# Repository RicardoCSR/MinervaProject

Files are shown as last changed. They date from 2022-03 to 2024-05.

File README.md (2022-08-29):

# MinervaProject

Registro Mestre de Projeto 

Bases e arquivos de apoio utilizados para o desenvolvimento do projeto:

STM32duino - IDE Arduino Ver.1 e Ver.2

- Fontes TTL 
https://github.com/FrankBoesing/fonts.git
- Display TFT SPI/I2C
https://github.com/Bodmer/TFT_eSPI
- FontConverter - 1
https://rop.nl/truetype2gfx/
- FontConverter - 2
https://oleddisplay.squix.ch/#/home
- RGB888 para RGB565
https://trolsoft.ru/ru/articles/rgb565-color-picker
- App (EM TESTE)
https://thunkable.com/#/

Nixie_Clock - Extensor de Sensores de Sobrevivência

Iniciando em 16/10/2021

Projeto Minerva da paixão pelos clássicos tubos Nixie desenvolvidos na década de 50 aos modernos display LCD, da inspiração veio junto o desafio de unir o antigo ao novo agregando diversos sensores para a apresentação de informações para uso e sobrevivência diário como:

- Pressão (mmHg)
- Temperatura (ºC e F)
- Umidade (%)
- Altitude
- sieverts (µSv e mSv)
- Hora/Data
- Calendário Completo
- Calculadora
- Grandezas e Medidas
- Estação do Ano (Primavera)
- Semana (Semana 39)
- Modo de ajustes dos parâmetros 

Sendo organizados pelos Menus:

Geiger                              - Apresenta Contagem por Segundo, Leitura Sieverts nSv/s
Dosimeter                           - Apresenta valor Dosimetro, Tempo de atualização, faixa de risco de Sv/h
Geiger GF                           - Apresenta gráfico dos valores apresentados nas 24 Horas do Geiger
Calendar                            - Apresenta Calendário
Timer                               - Apresenta Alarme, Contador e Tempo de Volta
Weather GF Temperature              - Apresenta gráfico dos valores apresentados nas 24 Horas do Temperatura
Weather GF Humidity                 - Apresenta gráfico dos valores apresentados nas 24 Horas do Umidade
Weather GF Atmosferic Pressure      - Apresenta gráfico dos valores apresentados nas 24 Horas do Pressão Atmosferica
Weather                             - Apresenta Temperatura, Umidade, Pressão Atmosférica, mínima e máxima e previsão via 
User                                - Apresenta Configurações básica de nome e imagem de Perfil
Calculator                          - Apresenta Calculadora de Operação Simples (Modendo ser extender a outros modelos)
Gerador de Sinais                   - Apresenta função de gerador de Sinais de 3.3V
Nixie Settings                      - Apresenta ajuste de animação Nixie
WiFi Settings                       - Apresenta Configurações de Acesso a rede externa
Settings                            - Apresenta Configurações de Ajuste da Tela

Database                            - Apresenta valores de todas as variaveis presentes (USO DESENVOLVIMENTO).

Componentes e suas caracteristicas

SN74141 : True Table // Podendo utilizar k155id1 ou SN74141
- D C B A #
- L, L, L, L 0
- L, L, L, H 1
- L, L, H, L 2
- L, L, H, H 3
- L, H, L, L 4
- L, H, L, H 5
- L, H, H, L 6
- L, H, H, H 7
- H, L, L, L 8
- H, L, L, H 9
- H, L, H, L N
- H, L, H, H N
- H, H, L, L N
- H, H, L, H N
- H, H, H, L N
- H, H, H, H N

ILI9486_DRIVER - Alimentação Ideal 3v3
TFT 8-BIT PARALLEL

Lista Terminais Utilizados STM32L476RG  29/08/2022

- R       Botao Hard Reset (Apenas para Desenvolvimento)

- PA0     TFT_RD
- PA1     TFT_WD
- PA2     
- PA3     
- PA4     TFT_DC
- PA5     
- PA6    
- PA7     
- PA8     TFT_D7
- PA9     TFT_D1
- PA10    TFT_D2
- PA11    
- PA12    
- PA15    

- PB0     TFT_CS
- PB1    
- PB2     
- PB3     TFT_D3
- PB4     TFT_D5
- PB5     TFT_D4
- PB6     
- PB7     
- PB8     
- PB9     
- PB10    TFT_D6
- PB12   
- PB13    
- PB14  
- PB15   

- PC0
- PC1     TFT_RST
- PC2
- PC3
- PC4
- PC5
- PC6
- PC7     TFT_D0
- PC8
- PC9
- PC10
- PC11
- PC12
- PC13   
- PC14    
- PC15    

- PD2

- PH0
- PH1

Lista Terminais Utilizados ESP32S  29/08/2022

- R       Botao Hard Reset

- GPIO0
- GPIO1
- GPIO2
- GPIO3
- GPIO4
- GPIO6
- GPIO7
- GPIO8
- GPIO9
- GPIO10
- GPIO11
- GPIO12
- GPIO13
- GPIO14
- GPIO15
- GPIO16
- GPIO17
- GPIO18
- GPIO19
- GPIO21
- GPIO22
- GPIO23
- GPIO25
- GPIO26
- GPIO27
- GPIO32
- GPIO33
- GPIO34
- GPIO35
- GPIO36
- GPIO39

*Projeto alterado para a Rev.3 sendo substituido o display ST7789 para o modelo ILI9486 de 480x320 em 8-Bit Paralelo pela velocidade de carregamento e estabilidade durante execuções e aplicações que envolvem banco de dados. O microcontrolador anterior STM32F401CCU6 substituido pelo modelo STM32L476RG de maior banda de memoria e expansão. Podendo ser substituido por um modelo mais economico.

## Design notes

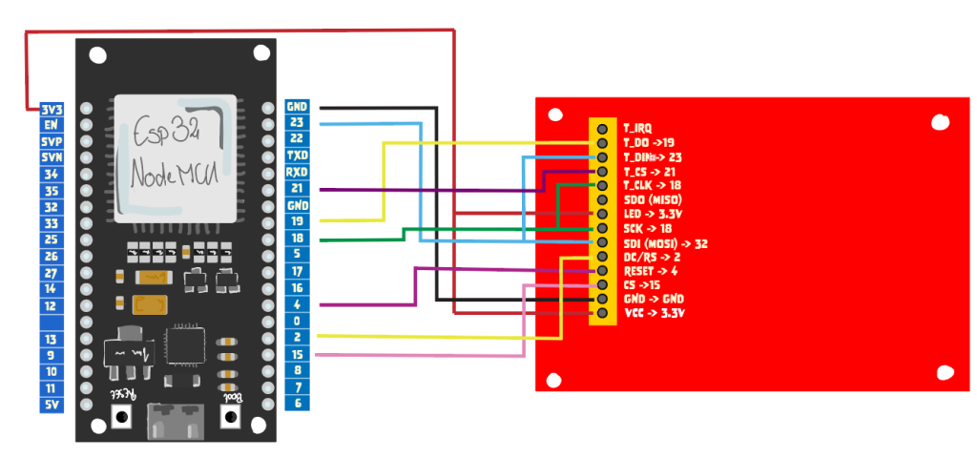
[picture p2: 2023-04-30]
esp32ScreenPinout.webp

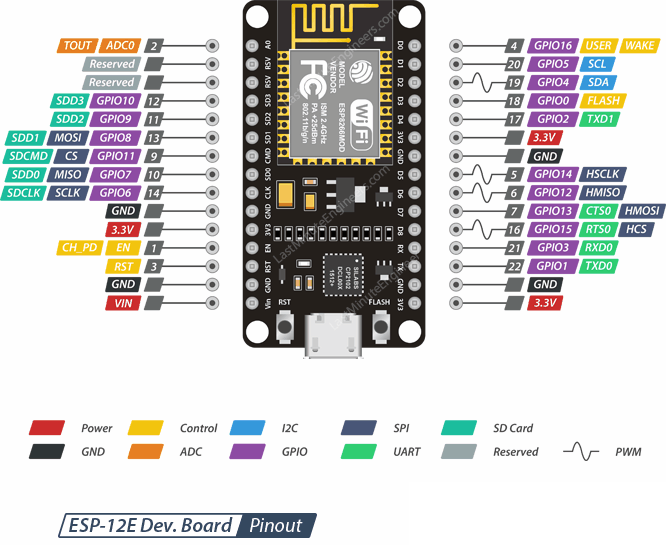
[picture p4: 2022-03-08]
ESP12E 8266.png

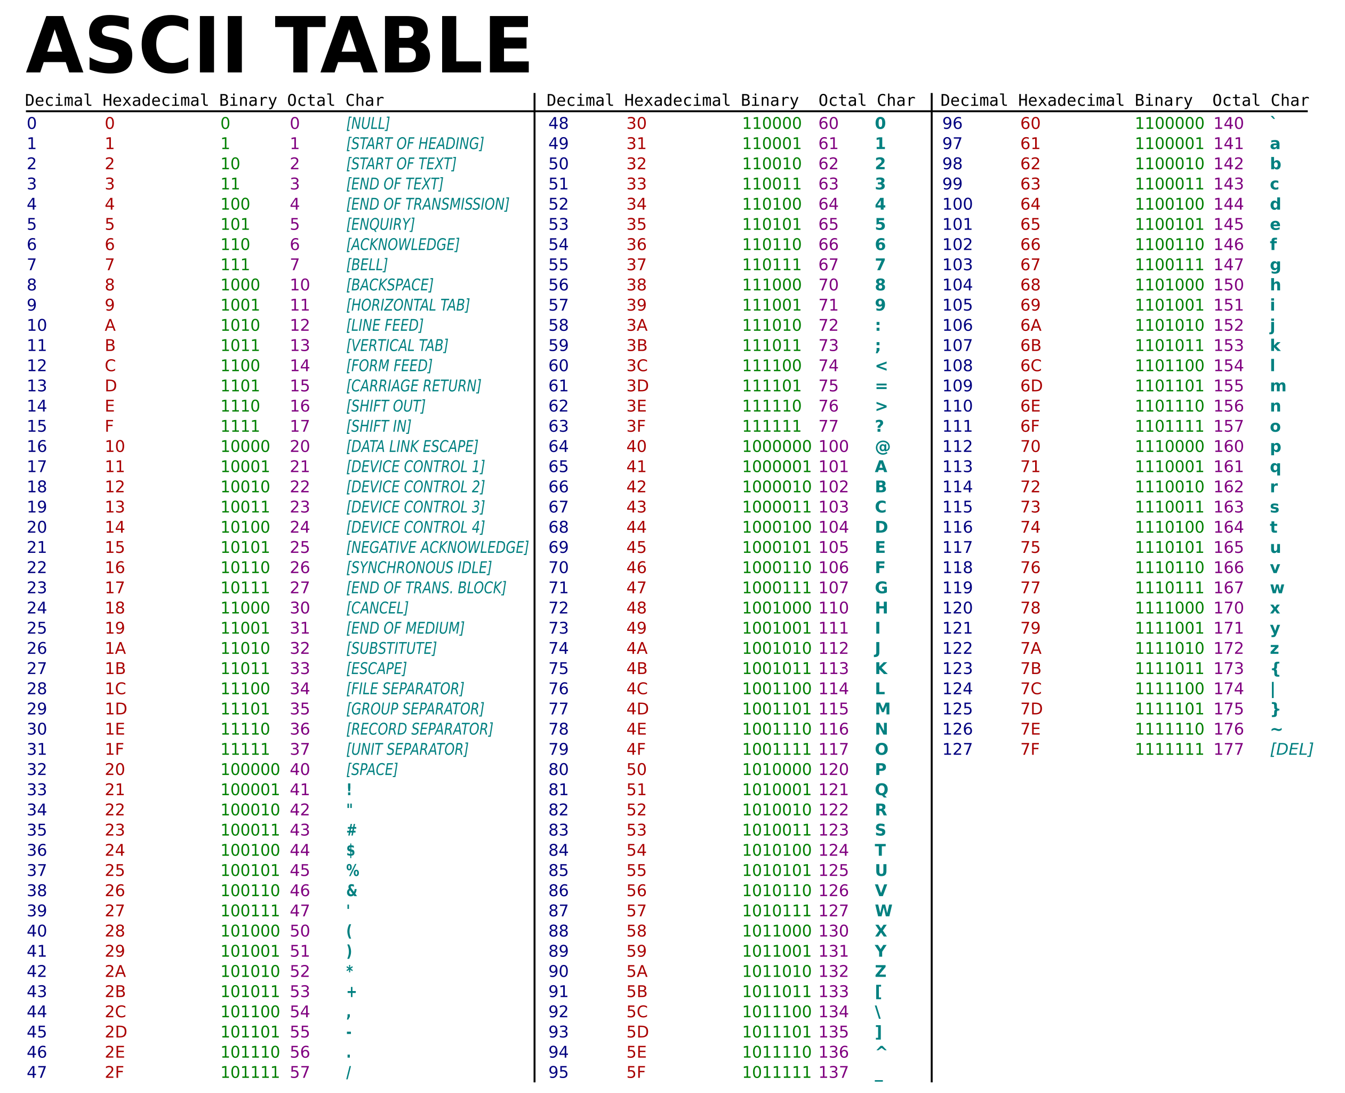
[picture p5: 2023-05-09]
ASCII-Table.svg.png

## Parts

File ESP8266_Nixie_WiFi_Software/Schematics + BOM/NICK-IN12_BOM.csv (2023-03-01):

ID | Name | Designator | Footprint | Quantity | Manufacturer Part | Manufacturer | Supplier | Supplier Part | LCSC Assembly
1 | 10uF | C3 | CAP_0603 | 1 | TCC0603X5R106M160CT | CCTC | LCSC | C380317
2 | 330 | R6,R7 | R0603 | 2 | 0603WAJ0331T5E | UniOhm | LCSC | C25231
3 | K155ID1/SN74141 | U3,U4,U5,U6 | DIP16 | 4
4 | TLP627-2(F) | U8 | PDIP-8_L9.5-W6.6-P2.54-LS8.0-BL | 1 | TLP627-2(F) | TOSHIBA | LCSC | C845530
5 | MMBT2222A,215 | Q1 | SOT-23-3_L2.9-W1.6-P1.90-LS2.8-BR | 1 | MMBT2222A,215 | Nexperia | LCSC | C179396 | Yes
6 | 74HC595D,118 | U1,U2 | SOIC-16_150MIL | 2 | 74HC595D,118 | Nexperia | LCSC | C5947 | Yes
7 | U-D-M5DD-W-1 | USB1 | MICRO-USB-TH_MICRO-USB-A14 | 1 | U-D-M5DD-W-1 | HRO | LCSC | C145795
8 | 1A FUSE | F1 | FUSE_0805 | 1 | SMD0805P110TF | Yenji Elec | LCSC | C393933
9 | 100nF | C1,C4,C5 | 0603 | 3 | C0603C104K5RACTU | KEMET | LCSC | C127833
10 | WS2812B | LED1,LED2,LED3,LED4,LED5 | LED-5050_4P | 5 | WS2812B | Worldsemi | LCSC | C114585
11 | NCH8200HV | PS1 | NCH8200HV-1 | 1 | NCH8200HV
12 | 10K | R1,R8,R9 | RES_0603 | 3 | PTFR0603D10K0P9 | ResistorToday | LCSC | C375971
13 | 20K | R2,R3,R4,R5 | 1210 | 4 | RC1210JR-0720KL | YAGEO | LCSC | C276323
14 | AMS1117-3.3_C351784 | U7 | SOT-223-3_L6.5-W3.4-P2.30-LS7.0-BR | 1 | AMS1117-3.3 | PUOLOP | LCSC | C351784
15 | 470uF | C2 | CASE-D_7343 | 1 | TAJD477M006RNJ | AVX | LCSC | C106188 | Yes
16 | SW_IN-12B | NIX1,NIX2,NIX3,NIX4 | PK_IN-12B | 4
17 | 1N5819 | D1 | SOD-323_L1.8-W1.3-LS2.5-RD | 1 | 1N5819WS | KEXIN | LCSC | C369937
18 | ESP-12E | ESP | WIFIM-SMD_ESP-12E | 1 | ESP-12E | Ai-Thinker | LCSC | C89297

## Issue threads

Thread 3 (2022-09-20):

Grafico Deslocado

RicardoCSR, 2022-09-20:
Durante a execução dos gráficos o mesmo não ultrapassa as **12 Horas** indicadas. _Verificar a conversão e sistema de armazenamento dos valores de escrita e posicionamento de barra._

RicardoCSR, 2023-04-30:
Falha apresentada com o valor const alterado com a nova versao do software

Closed 2023-04-30.

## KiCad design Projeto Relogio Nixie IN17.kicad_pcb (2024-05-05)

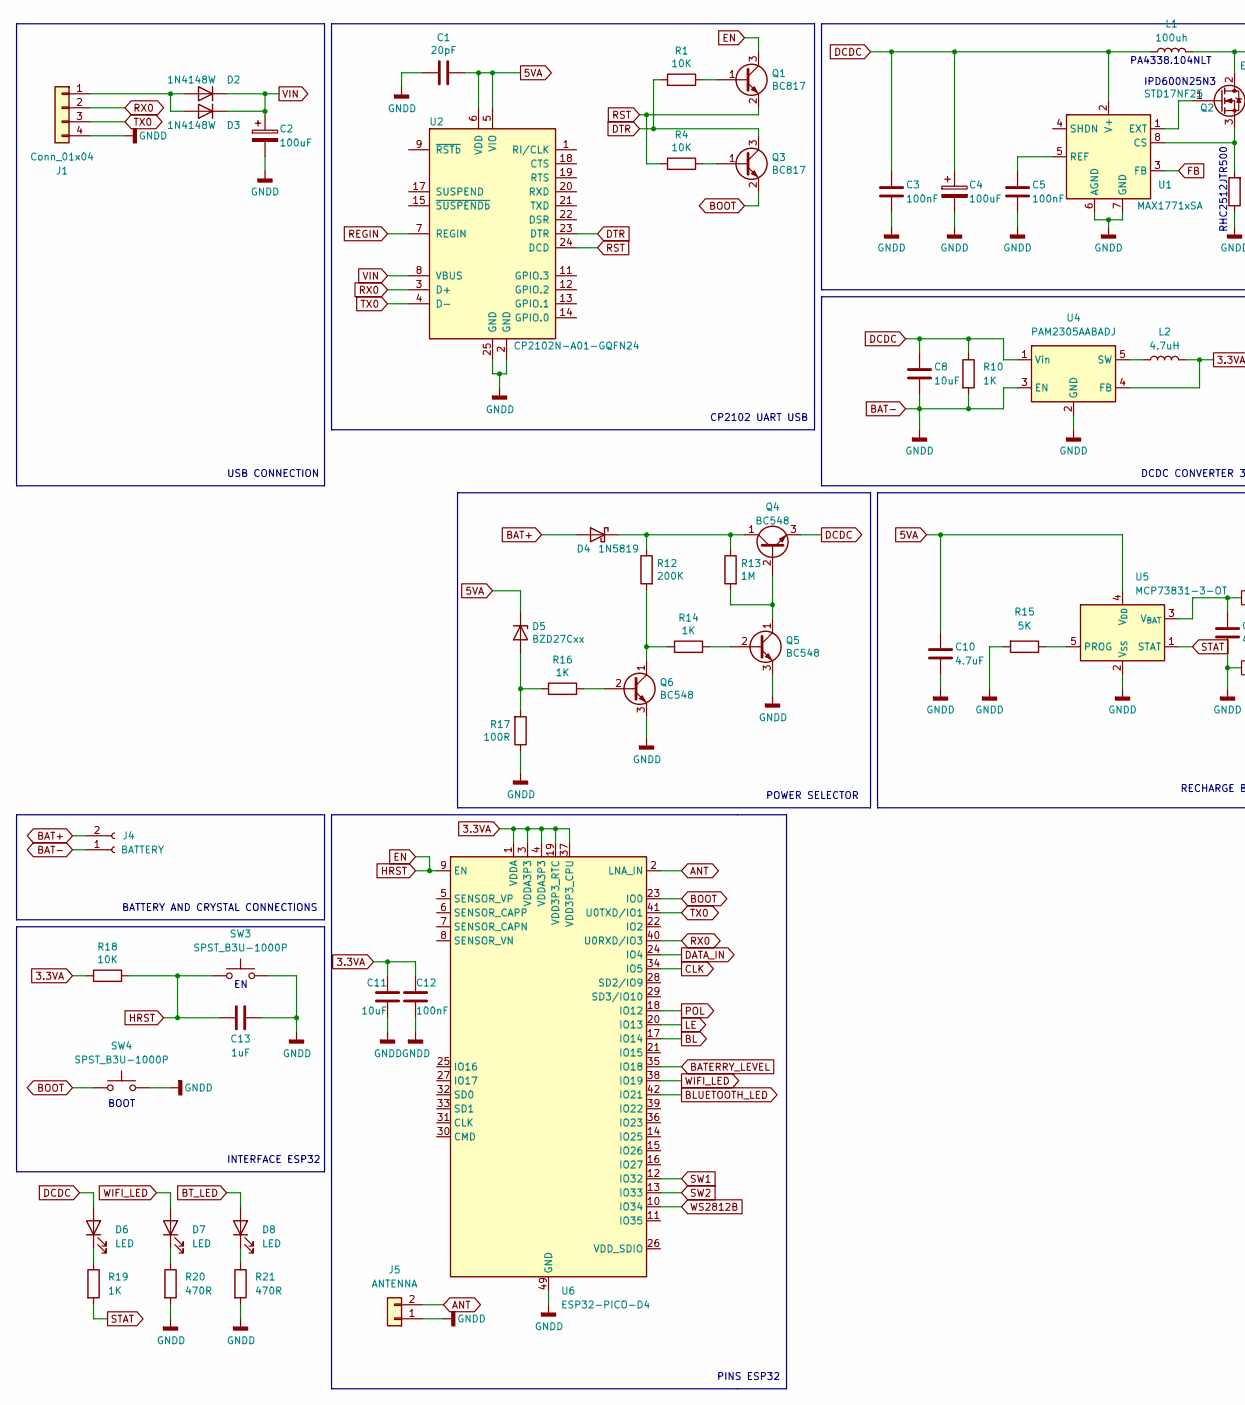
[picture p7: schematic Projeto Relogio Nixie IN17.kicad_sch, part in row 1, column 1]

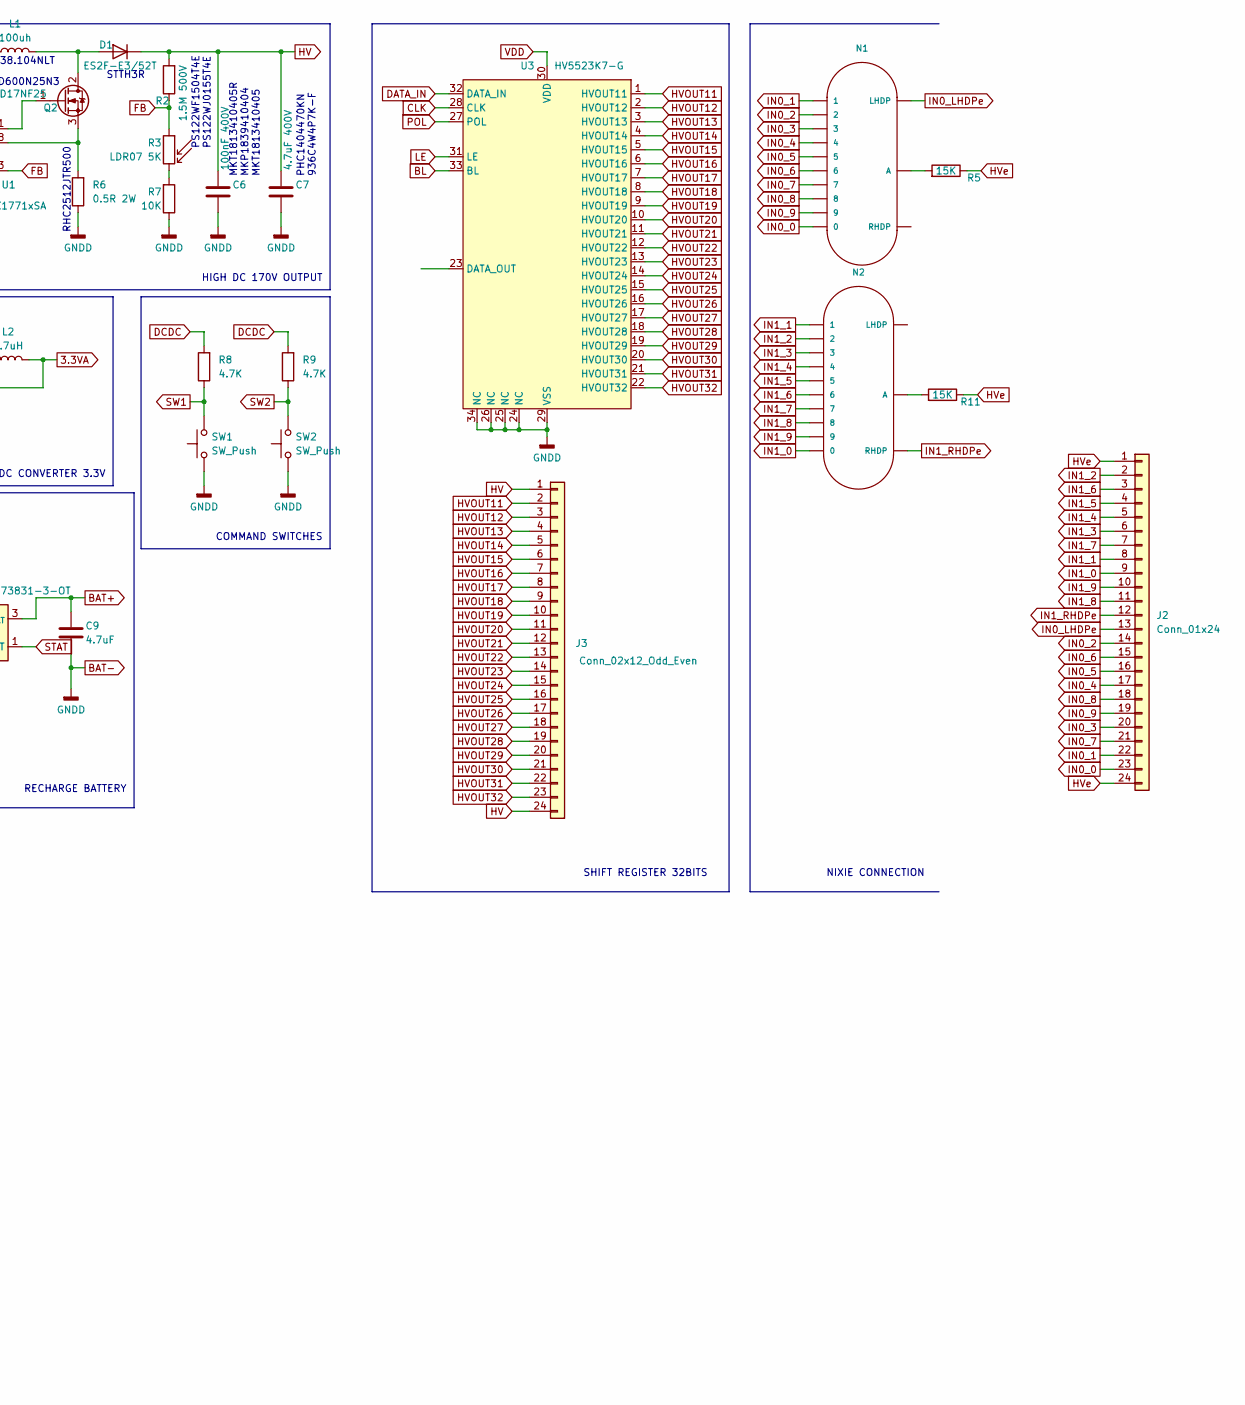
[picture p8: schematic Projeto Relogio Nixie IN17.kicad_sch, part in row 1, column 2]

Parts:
C1: 20pF; C_0805_2012Metric
C2, C4: 100uF; CP_EIA-1608-08_AVX-J
C3, C5, C12: 100nF; C_0805_2012Metric
C6: 100nF 400V; C_Axial_L5.1mm_D3.1mm_P10.00mm_Horizontal
C7: 4.7uF 400V; C_Axial_L5.1mm_D3.1mm_P10.00mm_Horizontal
C8, C11: 10uF; C_0805_2012Metric
C9, C10: 4.7uF; C_0805_2012Metric
C13: 1uF; C_0805_2012Metric
D1: ES2F-E3/52T; D_SMB
D2, D3: 1N4148W; D_SOD-123
D4: 1N5819; D_0805_2012Metric
D5: BZD27Cxx; D_2114_3652Metric
D6, D7, D8: LED; LED_1206_3216Metric
J1: Conn_01x04; Magnetic_01x04
J2: Conn_01x24; TE_2-1734839-4_1x24-1MP_P0.5mm_Horizontal
J3: Conn_02x12_Odd_Even; TE_2-1734839-4_1x24-1MP_P0.5mm_Horizontal
J4: BATTERY; PinHeader_1x02_P2.00mm_Vertical
J5: ANTENNA; PinHeader_1x02_P2.00mm_Vertical
L1: 100uh; L_Bourns-SRN8040_8x8.15mm
L2: 4.7uH; L_Bourns_SRP5030T
N1, N2: IN-16; nixies-us-IN-16
Q1, Q3: BC817; SOT-23
Q2: STD17NF25; TO-252-2
Q4, Q5, Q6: BC548; SOT-23
R1, R4, R7, R18: 10K; R_0603_1608Metric
R2: 1.5M 500V; R_2512_6332Metric_Pad1.40x3.35mm_HandSolder
R3: LDR07 5K; R_LDR_5.1x4.3mm_P3.4mm_Vertical
R5, R11: 15K; R_0603_1608Metric
R6: 0.5R 2W; R_2512_6332Metric_Pad1.40x3.35mm_HandSolder
R8, R9: 4.7K; R_0603_1608Metric
R10, R14, R16, R19: 1K; R_0603_1608Metric
R12: 200K; R_0603_1608Metric
R13: 1M; R_0603_1608Metric
R15: 5K; R_0603_1608Metric
R17: 100R; R_0603_1608Metric
R20, R21: 470R; R_0603_1608Metric
SW1, SW2: SW_Push; PinHeader_1x02_P2.00mm_Vertical
SW3, SW4: SPST_B3U-1000P; SW_SPST_B3U-1000P
U1: MAX1771xSA; SO-8_3.9x4.9mm_P1.27mm
U2: CP2102N-A01-GQFN24; QFN-24-1EP_4x4mm_P0.5mm_EP2.6x2.6mm
U3: HV5523K7-G; QFN-44-1EP_7x7mm_P0.5mm_EP5.15x5.15mm
U4: PAM2305AABADJ; TSOT-23-5
U5: MCP73831-3-OT; SOT-23-5
U6: ESP32-PICO-D4; QFN-48-1EP_7x7mm_P0.5mm_EP5.3x5.3mm

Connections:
3.3VA: C11.1, C12.1, L2.2, R18.2, U4.4 (FB), U6.1 (VDDA), U6.3 (VDDA3P3), U6.4 (VDDA3P3), U6.19 (VDD3P3_RTC), U6.37 (VDD3P3_CPU)
5VA: C1.1, C10.1, D5.1 (K), U2.5 (VIO), U2.6 (VDD), U5.4 (V_{DD}); also elsewhere on the board
ANT: J5.2, U6.2 (LNA_IN)
BAT+: C9.1, D4.2 (A), J4.2, U5.3 (V_{BAT})
BAT-: C1.2, C2.2, C3.2, C4.2, C5.2, C6.2, C7.2, C8.2, C9.2, C10.2, C11.2, C12.2, C13.2, J1.4, J4.1, J5.1, Q5.3 (E), Q6.3 (E), R6.1, R7.1, R10.2, R15.2, R17.1, R20.2, R21.2, SW1.1, SW2.1, SW3.3 (B), SW3.4 (B), SW4.3 (B), SW4.4 (B), U1.6 (AGND), U1.7 (GND), U2.2 (GND), U2.25 (GND), U3.24 (NC), U3.25 (NC), U3.26 (NC), U3.29 (VSS), U3.34 (NC), U4.2 (GND), U4.3 (EN), U5.2 (V_{SS}), U6.49 (GND)
BATERRY_LEVEL: U6.35 (IO18)
BL: U3.33 (BL), U6.17 (IO14)
BLUETOOTH_LED: U6.42 (IO21)
BOOT: Q3.2 (E), SW4.1 (A), SW4.2 (A), U6.23 (IO0)
BT_LED: D8.2 (A)
CLK: U3.28 (CLK), U6.34 (IO5)
DATA_IN: U3.32 (DATA_IN), U6.24 (IO4)
DCDC: C3.1, C4.1, C8.1, D6.2 (A), L1.1, Q4.3 (E), R8.2, R9.2, R10.1, U1.2 (V+), U4.1 (Vin)
DTR: Q3.3 (C), R1.2, U2.23 (DTR)
EN: C13.1, Q1.3 (C), R18.1, SW3.1 (A), SW3.2 (A), U6.9 (EN)
FB: R2.1, R3.1, U1.3 (FB)
HV: C6.1, C7.1, D1.1 (K), J3.1, J3.24, R2.2
HVOUT11: J3.2, U3.1 (HVOUT11)
HVOUT12: J3.3, U3.2 (HVOUT12)
HVOUT13: J3.4, U3.3 (HVOUT13)
HVOUT14: J3.5, U3.4 (HVOUT14)
HVOUT15: J3.6, U3.5 (HVOUT15)
HVOUT16: J3.7, U3.6 (HVOUT16)
HVOUT17: J3.8, U3.7 (HVOUT17)
HVOUT18: J3.9, U3.8 (HVOUT18)
HVOUT19: J3.10, U3.9 (HVOUT19)
HVOUT20: J3.11, U3.10 (HVOUT20)
HVOUT21: J3.12, U3.11 (HVOUT21)
HVOUT22: J3.13, U3.12 (HVOUT22)
HVOUT23: J3.14, U3.13 (HVOUT23)
HVOUT24: J3.15, U3.14 (HVOUT24)
HVOUT25: J3.16, U3.15 (HVOUT25)
HVOUT26: J3.17, U3.16 (HVOUT26)
HVOUT27: J3.18, U3.17 (HVOUT27)
HVOUT28: J3.19, U3.18 (HVOUT28)
HVOUT29: J3.20, U3.19 (HVOUT29)
HVOUT30: J3.21, U3.20 (HVOUT30)
HVOUT31: J3.22, U3.21 (HVOUT31)
HVOUT32: J3.23, U3.22 (HVOUT32)
HVe: J2.1, J2.24, R5.1, R11.1
IN0_0: J2.23, N1.0
IN0_1: J2.22, N1.1
IN0_2: J2.14, N1.2
IN0_3: J2.20, N1.3
IN0_4: J2.17, N1.4
IN0_5: J2.16, N1.5
IN0_6: J2.15, N1.6
IN0_7: J2.21, N1.7
IN0_8: J2.18, N1.8
IN0_9: J2.19, N1.9
IN0_LHDPe: J2.13, N1.LHDP
IN1_0: J2.9, N2.0
IN1_1: J2.8, N2.1
IN1_2: J2.2, N2.2
IN1_3: J2.6, N2.3
IN1_4: J2.5, N2.4
IN1_5: J2.4, N2.5
IN1_6: J2.3, N2.6
IN1_7: J2.7, N2.7
IN1_8: J2.11, N2.8
IN1_9: J2.10, N2.9
IN1_RHDPe: J2.12, N2.RHDP
LE: U3.31 (LE), U6.20 (IO13)
unnamed: D1.2 (A), L1.2, Q2.2 (D)
unnamed: D2.2 (A), D3.2 (A), J1.1
unnamed: D4.1 (K), Q4.1 (C), R12.1, R13.1
unnamed: D5.2 (A), R16.2, R17.2
unnamed: D6.1 (K), R19.1
unnamed: D7.1 (K), R20.1
unnamed: D8.1 (K), R21.1
unnamed: N1.A, R5.2
unnamed: N2.A, R11.2
unnamed: Q1.1 (B), R1.1
unnamed: Q2.1 (G), U1.1 (EXT)
unnamed: Q2.3 (S), R6.2, U1.8 (CS)
unnamed: Q3.1 (B), R4.1
unnamed: Q4.2 (B), Q5.1 (C), R13.2
unnamed: Q5.2 (B), R14.1
unnamed: Q6.2 (B), R16.1
unnamed: Q6.1 (C), R12.2, R14.2
unnamed: R3.2, R7.2
unnamed: C5.1, U1.5 (REF)
unnamed: L2.1, U4.5 (SW)
unnamed: R15.1, U5.5 (PROG)
POL: U3.27 (POL), U6.18 (IO12)
REGIN: U2.7 (REGIN)
RST: Q1.2 (E), R4.2, U2.24 (DCD)
RX0: J1.2, U2.3 (D+), U6.40 (U0RXD/IO3)
STAT: R19.2, U5.1 (STAT)
SW1: R8.1, SW1.2, U6.12 (IO32)
SW2: R9.1, SW2.2, U6.13 (IO33)
TX0: J1.3, U2.4 (D-), U6.41 (U0TXD/IO1)
VDD: U3.30 (VDD)
VIN: C2.1, D2.1 (K), D3.1 (K), U2.8 (VBUS); also elsewhere on the board
WIFI_LED: D7.2 (A), U6.38 (IO19)
WS2812B: U6.10 (IO34)

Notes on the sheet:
CP2102 UART USB
POWER SELECTOR
COMMAND SWITCHES
PA4338.104NLT
PHC1404470KN 936C4W4P7K-F
RHC2512JTR500
INTERFACE ESP32
DCDC CONVERTER 3.3V
IPD600N25N3
HIGH DC 170V OUTPUT
BATTERY AND CRYSTAL CONNECTIONS
BOOT
PINS ESP32
USB CONNECTION
STTH3R
SHIFT REGISTER 32BITS
NIXIE CONNECTION
PS122WF1504T4E PS122WJ0155T4E
RECHARGE BATTERY
MKT1813410405R MKP1839410404 MKT1813410405

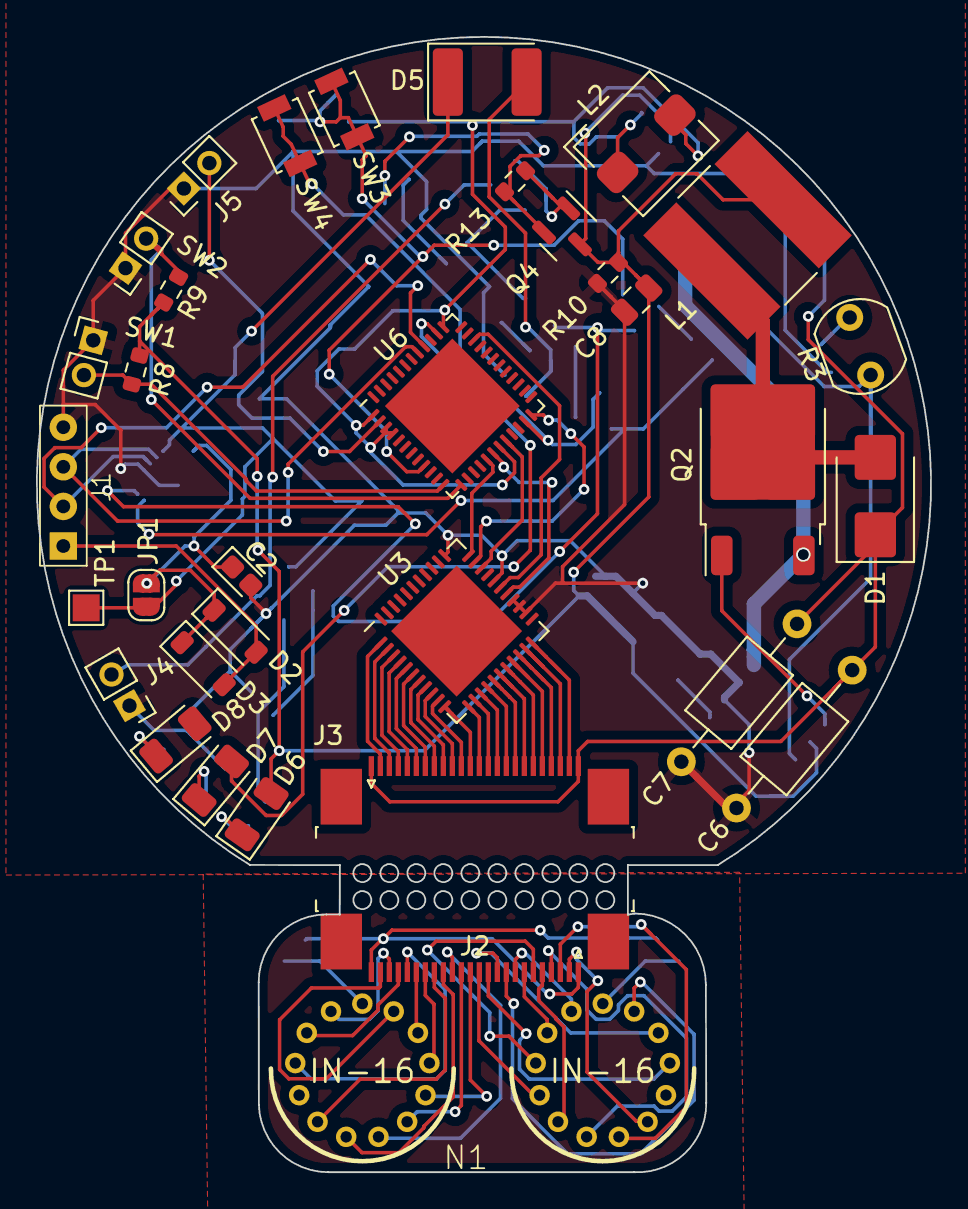
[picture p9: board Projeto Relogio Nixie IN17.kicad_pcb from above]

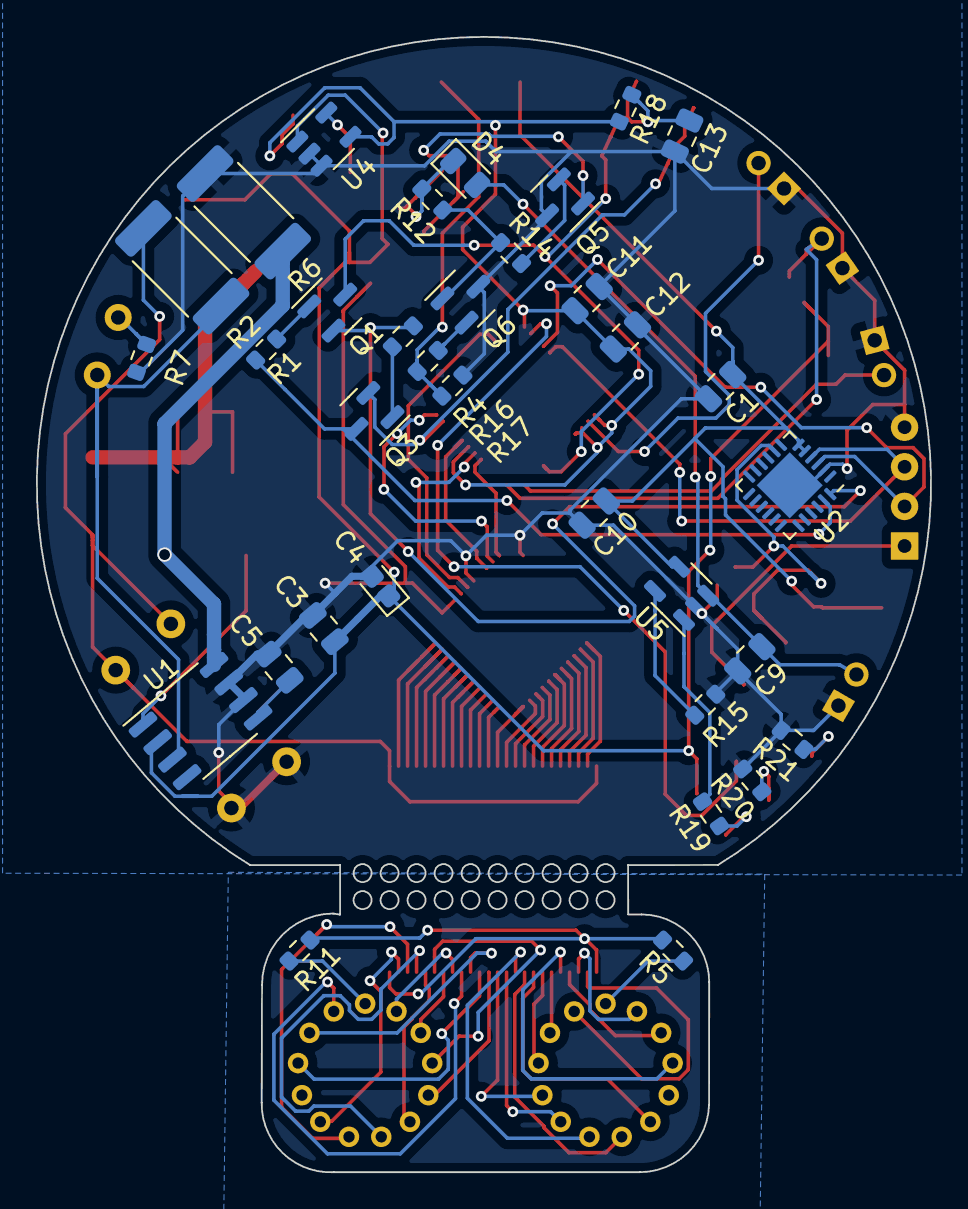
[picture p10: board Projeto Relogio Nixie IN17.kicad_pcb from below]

Board: 2 copper layers, 49.7 x 63.1 mm, 69 parts (34 on the bottom side), 90 nets.

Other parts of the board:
JP1: SolderJumper-2_P1.3mm_Open_RoundedPad1.0x1.5mm
TP1: 5VA; TestPoint_Pad_1.5x1.5mm

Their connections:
5VA: JP1.2 (B), TP1.1; also elsewhere on the board
VIN: JP1.1 (A); also elsewhere on the board

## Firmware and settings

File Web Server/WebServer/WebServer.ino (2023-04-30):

// Inclusão das bibliotecas
#include <WiFi.h>
#include <AsyncTCP.h>
#include <ESPAsyncWebServer.h>

// Instanciação do objeto da classe AsyncWebServer
AsyncWebServer server(80);

// Constantes das credenciais do WiFi
const char* ssid = "Ricardo-EvolutionPro-2G";
const char* password = "ricardo123";

void setup() {

  // Conecta-se ao Ponto de acesso com as credenciais fornecidas
  WiFi.begin(ssid, password);

  // disponibiliza o url "/"
  server.on("/", HTTP_GET, [](AsyncWebServerRequest * request) {
    const char index_html[] PROGMEM = R"====(

<!DOCTYPE html>
<html lang="pt-br">
    <link rel="stylesheet" href="https://fonts.googleapis.com/css?family=Lato:300">
    <head>
       <meta charset="utf-8"/>
       <title>Welcome</title>
       
    </head>

    <script>
        const scrollBars = document.querySelectorAll('.scroll-bar');

        function updateScrollBars() {
        const scrollTop = document.documentElement.scrollTop;
        const scrollHeight = document.documentElement.scrollHeight;
        const clientHeight = document.documentElement.clientHeight;
        const scrollRatio = scrollTop / (scrollHeight - clientHeight);

        scrollBars.forEach((scrollBar, index) => {
            if (index / 4 <= scrollRatio) {
            scrollBar.classList.add('active');
            } else {
            scrollBar.classList.remove('active');
            }
        });
        }

        window.addEventListener('scroll', updateScrollBars);

    </script>
    <style>
        @import url('https://fonts.googleapis.com/css?family=Lato&display=swap');

        body {
            margin: 0;
            padding: 0;
            justify-content: center;
        }
        .header-container {
            
            display: flex;
            justify-content: flex-end;
            align-items: center;
            padding: 10px;
            background-color: #161616;
            color: white;
        }

        img {
            width: 50px;
            height: 50px;
            margin-left: 2%;
            margin-top: 5px;
            position: absolute;
        }

        .header-buttons {
            display: flex;
            justify-content: flex-end;
            align-items: center;
        }

        .botao-header {
            font-family: 'Gill Sans', 'Gill Sans MT', Calibri, 'Trebuchet MS', sans-serif;
            font-size: 18px;
            color: #c0c0c0;
            background-color: transparent;
            border: none;
            padding: 10px;
            cursor: pointer;
            margin-left: 10px;
            width: 90px;
        }

        .botao-header2 {
            font-family: 'Gill Sans', 'Gill Sans MT', Calibri, 'Trebuchet MS', sans-serif;
            font-weight: 600;
            font-size: 18px;
            background-color: #fff;
            color: #000000;
            border: none;
            padding: 10px;
            border-radius: 5px;
            cursor: pointer;
            margin-left: 20px;
            width: 100px;
            margin-right: 2%;
        }

        .botao-header:hover {
            border: none;
            border-radius: 5px;
            background-color: #ffffff;
            color: #000000;
        }
        .page1 {
            align-items: center;
            width: 100%;
            height: 500px;
            background-color: #161616;
        }
        .page2 {
            align-items: center;
            width: 100%;
            height: 500px;
            background-color: #F67423;
        }
        .page3 {
            align-items: center;
            width: 100%;
            height: 500px;
            background-color: #BE1D69;
        }
        .page4 {
            align-items: center;
            width: 100%;
            height: 500px;
            background-color: #33ACD1;
        }
        .page5 {
            align-items: center;
            width: 100%;
            height: 500px;
            background-color: #343A40;
        }

        .allinone {
            padding-top: 50px;
            display: flex;
            width: 85%;
            margin: 0 auto;
        }
        .gradient-box {
            position: relative;
            background: linear-gradient(to bottom right, rgba(0, 219, 222, 0.9) 0%, rgba(75, 25, 102, 1)55%, rgba(30,25,30, 0.9)); /* define o gradiente na diagonal */
            padding: 0px; /* adiciona algum espaço interno para o conteúdo */
            color: #fff; /* define a cor do texto para branco */
            border-radius: 30px;
            height: 340px;
            width: 60%;
        }

        .gradientimage {
            margin-top: 10px;
            margin-left: 15px;
            width: 55px;
            height: 55px;
        }

        .caixa {
            padding-top: 75px;
            padding-left: 35px;
            margin: 0 auto;
            width: 450px;
            height: 200px;
        }
        .caixa button {
            margin-right: 15px;
            margin-bottom: 15px;
        }

        .coluna {
            border-radius: 15px;
            border: none;
            width: 70px;
            height: 70px;
        }

        .text-box1 {
            line-height: 0px;
            right: 250px;
            position: absolute;
        }
        
        .text-box1 p {
            margin-top: 35px;
            font-size: 54px;
            color: #ffffff;
            font-family: 'Lato', sans-serif;
            font-weight: bold;
        }

        .h1page1 {
            line-height: 25px;
            width: 50px;
            text-align: right;
            color: #c0c0c0;
            font-family: 'Lato', sans-serif;
            font-weight: 300;
            font-size: 20px;
            padding: 0;
            width: 241px;
        }

        .text-box2 {
            line-height: 0px;
            left: 50px;
            position: absolute;
        }
        
        .text-box2 p {
            margin-top: 125px;
            font-size: 54px;
            color: #ffffff;
            font-family: 'Lato', sans-serif;
            font-weight: bold;
        }

        .h1page2 {
            line-height: 25px;
            width: 50px;
            text-align: left;
            color: #c0c0c0;
            font-family: 'Lato', sans-serif;
            font-weight: 300;
            font-size: 20px;
            padding: 0;
            width: 241px;
        }

        .text-box3 {
            text-align: center;
            line-height: 0px;
            left: 30%;
            position: absolute;
        }
        
        .text-box3 p {
            margin-top: 75px;
            font-size: 54px;
            color: #ffffff;
            font-family: 'Lato', sans-serif;
            font-weight: bold;
        }

        .h1page3 {
            margin-left: 85px;
            line-height: 25px;
            text-align: center;
            color: #c0c0c0;
            font-family: 'Lato', sans-serif;
            font-weight: 300;
            font-size: 20px;
            padding: 0;
            width: 241px;
        }

        .text-box4 {
            line-height: 0px;
            left: 100px;
            position: absolute;
        }
        
        .text-box4 p {
            margin-top: 125px;
            font-size: 54px;
            color: #ffffff;
            font-family: 'Lato', sans-serif;
            font-weight: bold;
        }

        .h1page4 {
            line-height: 25px;
            width: 50px;
            text-align: left;
            color: #c0c0c0;
            font-family: 'Lato', sans-serif;
            font-weight: 300;
            font-size: 20px;
            padding: 0;
            width: 275px;
        }

        .btn {
            display: flex;
            justify-content: center;
            align-items: center;
            position: fixed;
            bottom: 10px;
            right: 10px;
            width: 50px;
            height: 50px;
            border-radius: 25px;
            background-color: #808080;
            text-decoration: none;
        }
        .btn:hover {
            transition: 250ms;
            color: #06D2DA;
        }
        
        .knowmore {
            color: #c0c0c0;
            font-family: 'Lato', sans-serif;
            font-weight: 300;
            font-size: 20px;
            border: none;
            background-color: #F67423;
        }

        .knowmore:hover {
            cursor: pointer;
        }
        
    </style>
    <body>
        <div class="page1">
            <div header="Content-Type" "background-color: #191919">
                <img src="blackmufoxpng.png" alt="Logo da Empresa">
                <header class="header-container">
                    <button class="botao-header">About</button>
                    <button class="botao-header">Screens</button>
                    <button class="botao-header">Connect</button>
                    <button class="botao-header2">Settings</button>
                </header>
            </div>
            <div class="page1"> 
                <div class="allinone">
                    <div class="gradient-box">
                        <img src="blackmufoxpng.png" class = "gradientimage" alt="Logo da Empresa">
                        <div class="caixa">
                            <div class="linha">
                                <button class="coluna" style="background-color: #f67a23;">
                                <button class="coluna" style="background-color: #f1a71f;">
                                <button class="coluna" style="background-color: #eb6052;">
                                <button class="coluna" style="background-color: #5fbc8d;">
                                <button class="coluna" style="background-color: #e91b5b;">
                            </div>
                            <div class="linha">
                                <button class="coluna" style="background-color: #eb6052;">
                                <button class="coluna" style="background-color: #58d160;">
                                <button class="coluna" style="background-color: #33acd1;">
                                <button class="coluna" style="background-color: #e46837;">
                                <button class="coluna" style="background-color: #15d9e2;">
                            </div>
                            <div class="linha">
                                <button class="coluna" style="background-color: #189b8d;">
                                <button class="coluna" style="background-color: #be1d69;">
                                <button class="coluna" style="background-color: #343a40;">
                                <button class="coluna" style="background-color: #9a54d8;">
                                <button class="coluna" style="background-color: #6a6a6a;">
                            </div>
                          </div>
                          
                    </div>
                    <div class="text-box1">
                        <p>All in One</p>
                        <h1 class="h1page1">Configure your <br> 
                            device using the <br> 
                            web access with <br> 
                            no need of a <br> 
                            account or <br> 
                            Mainframe.</h1>
                    </div> 
                </div>                  
            </div>
            <div class="page2"> 
                <div class="text-box2">
                    <p>Geiger Measurer</p>
                    <h1 class="h1page2">Measure the alfa and 
                        <br> beta radiations the <br> 
                        electron and 4He of the <br> 
                        Thorium, Radio, Uranium, <br> 
                        Plutonium decay. <br><br>
                        <button class="knowmore"><i>Want know more?</i></button></h1>
                </div> 
            </div>
            <div class="page3"> 
                <div class="text-box3">
                    <p>Compass System</p>
                    <h1 class="h1page3">Full system with compass <br> 
                        and gyroscope.</h1>
                </div> 
            </div>
            <div class="page4"> 
                <div class="text-box4">
                    <p>Weather System</p>
                    <h1 class="h1page4">By usiing the Temperature, <br>
                        Humidity and Atmospheric <br>
                        pressure data, find the possible <br>
                        weather forecast.</h1>
                </div> 
            </div>
            <div class="page5"> 
                <div class="text-box4">
                    <p>Nixie Tube Clock</p>
                    <h1 class="h1page4">Show the time in the <br>
                        old style of orange Neon <br>
                        working perfect in <br>
                        dark and light places.</h1>
                </div> 
                <section></section>
                <a href="#" class="btn"></a>
            </div>
        </div>
        
    </body>
</html>

    )===="; // grande matriz de caracteres
    request->send_P(200, "text/html", index_html); // Envia a resposta
  });

  // Servidor começa à ouvir os clientes
  server.begin();
}

void loop() {}

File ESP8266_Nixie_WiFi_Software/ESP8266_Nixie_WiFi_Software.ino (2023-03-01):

/*
PCF8574
Alimentação 2.6 a 3.6V

Sequencia Flash Nixie 
6 7 5 8 4 3 9 2 0 1 

SN74141 : True Table
D C B A #
L,L,L,L 0
L,L,L,H 1
L,L,H,L 2
L,L,H,H 3
L,H,L,L 4
L,H,L,H 5
L,H,H,L 6
L,H,H,H 7
H,L,L,L 8
H,L,L,H 9
H,L,H,L N
H,L,H,H N
H,H,L,L N
H,H,L,H N
H,H,H,L N
H,H,H,H N


ESP8266 - Alimentação Ideal 3v3 possível 5V mas com aquecimento

R       Botao Hard Reset

RST     Alimentacao LDR
EN

ADC0    LDR Sensor

GPIO0   TRIGGER_PIN
GPIO1   NÃO UTILIZÁVEL
GPIO2   Anode Nixie A        
GPIO3   Anode Nixie B
GPIO4   SDA Micro STM32 (Slave)
GPIO5   SCL Micro STM32 (Slave)
GPIO6   Anode Nixie C
GPIO7   Anode Nixie D
GPIO8   NÃO UTILIZÁVEL
GPIO9   NÃO UTILIZÁVEL
GPIO10  Botão Hibernar
GPIO11  NÃO UTILIZÁVEL
GPIO12  Botão Menu
GPIO13  Pino Nixie A
GPIO14  Pino Nixie B  
GPIO15  Pino Nixie C
GPIO16  Pino Nixie D

Acessa o canal via GPIO16 
#define 16 XXXX


//------------------------------- VALORES AJUSTAVEIS PELO USUÁRIO --------------------

const char *userNameWiFi = "MinervaProject";
const char *passWordWiFi = "MinervaProject";

int compareTimesMins = 0;

float updateNixie = 7;    // Variavel armazena taxa de atualização
int speedEffect = 25;       // Taxa de atualização do Efeito


//  Canal de ajuste do ST7789 criar uma pagina para o ajuste da frequência de atualização
//  indicar sendo de 5 ~ 10

//  2.0 ~ 6.9  = taxa atualização não visivel
//  7.0 ~ 7.9  = taxa atualização visivel leve
//  8.0 ~ 10.0 = taxa atualização visivel forte



//------------------------------- ARMAZENAMENTO DE DADOS E COMPARADORES ---------------
  // DADOS NIXIE

unsigned long nixieEffect = millis();

byte effectModeNixie = 1;
//effectModeNixie = 0 Animação Nixie desativado
//effectModeNixie = 1 Animação Nixie estilo Metro
//effectModeNixie = 2 Animação Nixie Númerico 

int numberArray[4] = { 0, 0, 0, 0}; // Armazena os dados de cada flashNixie para cada Nixie
int flashNixie = 0;         // Armazena valor para inserção no Driver
int nixieCounts = 0;        // Identifica o Pino a ser acionado do Driver
int nixieAnode = 0;         // Identifica o Pino para o efeito refresh
int compareTimeMins;        // Armazena tempo Minutos (ADICIONAR MESMO DA FUNCAO PRINCIPAL)
int* prt;                   // Corrige falha de Processadores ARM

  // DADOS NTC
unsigned int localPort = 8888;  

int lowerHours;             // Armazena dados de Hora 2
int upperHours;             // Armazena dados de Hora 1
int lowerMins;              // Armazena dados de Minuto 2
int upperMins;              // Armazena dados de Minuto 1
int lowerSeconds;           // Armazena dados de Segundos 2
int upperSeconds;           // Armazena dados de Segundo 1

// NTP Servers:
static const char ntpServerName[] = "us.pool.ntp.org";
//static const char ntpServerName[] = "time.nist.gov";
//static const char ntpServerName[] = "time-a.timefreq.bldrdoc.gov";
//static const char ntpServerName[] = "time-b.timefreq.bldrdoc.gov";
//static const char ntpServerName[] = "time-c.timefreq.bldrdoc.gov";
//static const char ntpServerName[] = "server 0.br.pool.ntp.or";
//static const char ntpServerName[] = "server 1.br.pool.ntp.or";
//static const char ntpServerName[] = "server 2.br.pool.ntp.or";
//static const char ntpServerName[] = "server 3.br.pool.ntp.or";
//static const char ntpServerName[] = "a.st1.ntp.br";
//static const char ntpServerName[] = "b.st1.ntp.br";
//static const char ntpServerName[] = "c.st1.ntp.br";
//static const char ntpServerName[] = "d.st1.ntp.br";
//static const char ntpServerName[] = "gps.ntp.br";

const int timeZone = -3;     
const int NTP_PACKET_SIZE = 48; // NTP time is in the first 48 bytes of message
byte packetBuffer[NTP_PACKET_SIZE]; //buffer to hold incoming & outgoing packets

#define TRIGGER_PIN 0           // ESTADO WI-FI

#define pinAnode0 4             // Pino Nixie Anodo Hora 1 
#define pinAnode1 3             // Pino Nixie Anodo Hora 2
#define pinAnode2 10            // Pino Nixie Anodo Minuto 1
#define pinAnode3 12            // Pino Nixie Anodo Minuto 2

#define driverPinA 13           // Pino Driver Catodo A
#define driverPinB 14           // Pino Driver Catodo B
#define driverPinC 15           // Pino Driver Catodo C
#define driverPinD 16           // Pino Driver Catodo D

#include <TimeLib.h>
#include <ESP8266WiFi.h>
#include <WiFiUdp.h>
#include <WiFiManager.h> 

// ------------------------------- INSTANCIAS DAS BIBLIOTECAS --------------------------

WiFiUDP Udp;
WiFiManager wm; 
WiFiManagerParameter custom_field; 


time_t getNtpTime();
void digitalClockDisplay();
void printDigits(int digits);
void sendNTPpacket(IPAddress &address);

void setup() {
  Serial.begin(115200);

  Serial.setDebugOutput(true);  
  pinMode(TRIGGER_PIN, INPUT);
  delay(1000);

  pinMode(pinAnode0, OUTPUT);
  pinMode(pinAnode1, OUTPUT);
  pinMode(pinAnode2, OUTPUT);
  pinMode(pinAnode3, OUTPUT);
  
  pinMode(driverPinA, OUTPUT);
  pinMode(driverPinB, OUTPUT);
  pinMode(driverPinC, OUTPUT);
  pinMode(driverPinD, OUTPUT);

  WiFi.mode(WIFI_STA); // explicitly set mode, esp defaults to STA+AP  
  int customFieldLength = 40;
  //WiFi.disconnect();

  while (WiFi.status() != WL_CONNECTED) {
    delay(500);
    Serial.print(".");

    const char* custom_radio_str = "<br/><label for='customfieldid'>Custom Field Label</label><input type='radio' name='customfieldid' value='1' checked> One<br><input type='radio' name='customfieldid' value='2'> Two<br><input type='radio' name='customfieldid' value='3'> Three";
    new (&custom_field) WiFiManagerParameter(custom_radio_str); // custom html input
    
    wm.addParameter(&custom_field);
    wm.setSaveParamsCallback(saveParamCallback);

    // custom menu via array or vector
    // 
    // menu tokens, "wifi","wifinoscan","info","param","close","sep","erase","restart","exit" (sep is seperator) (if param is in menu, params will not show up in wifi page!)
    // const char* menu[] = {"wifi","info","param","sep","restart","exit"}; 
    // wm.setMenu(menu,6);
    std::vector<const char *> menu = {"wifi","info","param","sep","restart","exit"};
    wm.setMenu(menu);

    // set dark theme
    wm.setClass("invert");


    //set static ip
    //wm.setSTAStaticIPConfig(IPAddress(10,0,1,99), IPAddress(10,0,1,1), IPAddress(255,255,255,0)); // set static ip,gw,sn
    // wm.setShowStaticFields(true); // force show static ip fields
    // wm.setShowDnsFields(true);    // force show dns field always

    // wm.setConnectTimeout(20); // how long to try to connect for before continuing
    wm.setConfigPortalTimeout(180); // auto close configportal after n seconds
    // wm.setCaptivePortalEnable(false); // disable captive portal redirection
    // wm.setAPClientCheck(true); // avoid timeout if client connected to softap
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

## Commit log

2022-02-26 Update README.md
    Atualização de dados do projeto.
2022-02-26 Add files via upload
    Plataforma utilizada:
    Arduino (STM32duino)
    Upload via ST-Link
    Plataforma de desenvolvimento Sublime Text 3
2022-03-02 Update README.md
    Atualização dos dados e implementação de novos conteúdos.
2022-03-05 Create Figma Link
    Arquivo de origem do site Figma, onde os design estão em desenvolvimento.
2022-03-05 Update README.md
    Inclusão dos pinos ESP32S e atualização para RMP.
2022-03-05 Update README.md
    Incluídos fontes utilizadas para o desenvolvimento do Projeto
2022-03-06 Update README.md
    Atualização de informações do projeto
2022-03-08 Add files via upload
    Atualização do Programa conforme o documento Figma Link
    Adicionados:
    Simbologia WiFi Level 1, 2 e 3
    Simbologia WiFi Offline
    Simbologia Baterias batteryStyleMode = 0;
    Simbologia Baterias batteryStyleMode = 1;
2022-03-09 Update README.md
    Inclusão do site de conversão de RGB888 para 565
2022-03-09 Add files via upload
    Inclusão dos arquivos de Lato Regular tamanho 10 e 12.
    Inclusão no programa das batteryStyleMode 2 e 3
    Inclusão no programa do Modo Geiger geigerStyleMode0 em progresso. 2046 ~ 2096.
2022-03-10 Add files via upload
    inclusão dosimeterStyleMode0 e paleta de cores atualizadas.
2022-03-13 Add files via upload
    Incluido calendarStyleMode0, timerStyleMode0, ajustTimeStyleMode0, ajustDataStyleMode0, ajustBrightStyleMode0
    Iniciado procedimento de correção de bugs operacionais configuração e alinhamento dos dados para apresentação dos dados as páginas gerados.
2022-03-13 Add files via upload
    Alterado PA4 e PA6 Sensor Gueiger e Sensor LDR
    Incluído ajustes do Menu Geiger, sendo incluido sistema de média no gráfico sem glitch de repetição.
2022-03-18 Add files via upload
    Inclusão e teste de sequencia Nixie
2022-03-29 Add files via upload
    Ajustes de escala e correção do Dosimeter.
2022-04-04 Add files via upload
    Adicionado gráficos de Temperatura, Umidade, e Pressão Atm. incluído pino EN para identificação do carregador e niveis de bateria.
    #Corrigir corte nos gráficos e incluir restauração dos dados após sair do Menu.
2022-04-04 Update README.md
    Inclusão da página web: https://thunkable.com/#/ criação de Aplicativos Android
2022-04-04 Add files via upload
    Teste e configuração para operação com ESP32
2022-04-05 Add files via upload
    Ajuste para testes e configuração da rede WiFi
2022-04-08 Add files via upload
    Arquivos testes para configuração das páginas Web para ESP32 atualizadas para o WiFiManager
2022-04-08 Add files via upload
    Pinos e configuração para aplicação em PCB do ESP32 comunicação e gravação RS232
2022-04-09 Add files via upload
    Autalização e inclusão de novos elementos para a página Web
2022-04-10 Add files via upload
    Atualização e execução de layout HTML
2022-04-12 Delete Teste_WiFi_Communication.ino
    Movido para Pasta teste_WiFi_Communication
2022-04-14 Add files via upload
    Remoção da Função Nixie() sendo movimentada para o ARM ESP32
2022-04-16 Add files via upload
    Arquivos KiCad
    [ARM Circuit.sch, Geiger Circuit.sch, Nixie.sch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]
